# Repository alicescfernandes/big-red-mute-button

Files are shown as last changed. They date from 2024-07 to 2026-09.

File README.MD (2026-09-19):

# [WIP] 🔴 Big Red Button (BRB for short)

## A wireless bluetooth button that does anything

This is a Bluetooth-controlled device that emulates a Bluetooth mouse, allowing it to appear as a standard input device to Windows and macOS. This enables it to be paired with the OS without installing any drivers or additional software. This is the V3 version of the button, where i experimented a lot with parts and printed circuit boards!

The device uses BLE (Bluetooth Low Energy) to communicate wirelessly via Bluetooth characteristics (think of it like wireless variables) that can be changed by a device that is authenticated with the device.

## WHy & how did i build this?

What led me to redo the BRB (🔴) _again_ was the desire to make the perfect button, and that meant that v1 and v2 were not perfect. For one, the v2 project kept restarting on battery, and i just had way to many wires. The button itself was big and noisy, and used a 12V LED that i could barely see and needed a boost converter to take 5V into 12V.

For this revision, i wanted all on 5V, which meant rebuilding the button itself. Since i had a few spare keyboard Cherry MX switches and a Neoixel ring that i ended up storing away, i've settled on using those parts for this revision. For the dome part, i decided to take apart the red button of V1, and repurposed the battery of V2.

I experimented _a lot_ on this revision. Went with magnetic connectors for the bottom and top part, custom made PCBs (i designed them myself, and even milled one on a CNC device), a big (i mean _huge_) keycap for the Cherry MX with 12 powerful 5V LEDS! The "net new" parts ended up being a IP5603 module to manage the charging of the battery and a few accessory parts for the enclosure.

I ended designing 2 versions of both top and bottom PCB's, a surface mount version and a through hole version that could be milled on a CNC, I ended up designing them as a experiment and learning exercise!

### Why not TP4056?

I researched a lot about battery management IC's, and had to make a fiww design options early on, so i could find the chip that i would need. My requirements were:
- Needs a power path, meaning that it can be used while charging
- Needs to be suitable for low charging currents, or the charging current should be configurable
- Needs to be suitable for LiPo pouch cells.
- It would be nice to have I2C for battery percentage
- It would be nice to have an integrated boost converter 

After my research, ended up with a few options:  TP4056, IP5603, BQ25185, BQ25895, MCP73871 and ETA9740. They all have advantages:
- TP4046 is the simplest of them all, but doesn't transform the output of the battery to 5V, and i really need those 5V. You can definitely add a boost circuit for the output, but i didn't want to bother with that
- IP5603 does transform the power to 5V, but it only provides visual indicators for battery percentage. It's also relatively simple to build a circuit around this one. However, this chip uses a pushbutton to enable / disable the battery power and it's not suitable for LiPo pouch cells as it charges with high currents, more suitable for 18650 battery packs
- ETA9740 is very similar to IP5603, however it doesn't allow me to configure a smaller charge current than 2amps, and i need a charging rate of 300ma
- BQ25895 can provide a 5V power and battery percentage information over I2C protocol, which is awesome, but the reference circuit is a bit too scary for me to try, and it's a bit outta my league.
- BQ25185 ticks a lot of those boxes. It has a power path, i can configure to charge on low currents which makes it suitable for my LiPo cell. However, i'll have to add my own boost converter to get stable 5V and 1A out of the battery.
- MCP73871 is in some ways just a simple version of the BQ25185, with less features and a easier footprint to handle. It still needs to boost converter.

Ultimately, I decided to go with a BQ25895 +  TPS61023 combo, since i was able to find a test board that i could use on a breadboard to validate the design.

### Software used
- EasyEDA for schematic and PCB Design
- Flatcam for board milling
- Arduino IDE to code the ESP32's

#### Parts List (Bottom)
- ESP32-S3-Tiny
- BQ25185DLHR (Battery Charger)
     - configured for 300ma charge rate 
     - and 500ma input rate
     - 74438357010 Inductor (recommended by datasheet)
     - X5R Capacitors (recommended by datasheet, for cost)
- TPS61023DRLR
    - Configured for 5V, 1.1A
- L584070 (CELLEVIA) LiPo Battery
- Panel-mounted USB Port (with resistors on CC1 & CC2)

#### Parts List (Top)
- Cherry MX Red
- 12 WS2812 LEDs wired in a ring configuration 

### Detailed PCB Specs

The electronics themselves are wired on two separate PCBs: the top PCB that has the lights and buttons, and the bottom PCB handles the power and logic control. The PCB's are then connected together.

The PCB's were designed to be 2 Layers (Signal, Ground) on the bottom PCB  and 4 layers (VCC, Ground, Signal, Ground) on the Top PCB

## Inner workings

### Mouse Emulation

This device uses Bluetooth Low Energy (BLE) to emulate a mouse via the HID (Human Interface Device) profile. By creating a fake mouse, it appears to the host (Windows or macOS) as a standard mouse. And with BLE, we can create our own functionalities (custom characteristics) and attach it to the fake mouse device, and have some python code to write on those.

The fake mouse is needed for Windows and MacOS, that refuse to accept input of devices that are don't provide HID functionality, but i assure you that the mouse is controlled by the device, it just emulates the device characteristics of a mouse.

### BLE Services and Characteristics

In Bluetooth Low Energy (BLE), communication is structured around services and characteristics. A service is a collection of related functionality, like a HID service for mouse input or a battery service for reporting battery level. Each service contains one or more characteristics, which represent individual pieces of data that can be read, written, or notified.

For example, this device implements:

- A HID service, which includes characteristics to send mouse reports (movement or button presses).
- A Battery service, with a battery level characteristic which exposes the current battery level to the connected device.
- A Custom Button service, with a single characteristic which notifies the host when the physical button is pressed.

### You said it could do anything?

Yes, with the help of some python code we can make the mic mute globally, trigger a lock screen or just rick-roll somebody. The host application was built using Rumps and Python to build a menu bar GUI. I'm not sure if this is compatible with Linux and Windows but at least works on Mac (:joy:)

## Assembling one yourself

### Bill of Materials (if you wanna build it yourself)

- [Waveshare ESP32-Tiny](https://www.waveshare.com/esp32-s3-tiny.htm) or a [Seed XIAO ESP32-S3](https://www.seeedstudio.com/XIAO-ESP32S3-p-5627.html)
- [Big Dome Pushbutton](https://www.sparkfun.com/products/9181), you will need just the "dome" part
- [Adafruit BQ2185 Charger with 5V Booster](https://www.adafruit.com/product/6106) or [SeedStudio Lipo Rider Plus](https://www.seeedstudio.com/Lipo-Rider-Plus-p-4204.html), both work for Li-ion Pouch Cells, and both are USB-C
- USB power input via:
    - A USB Panel mount to 2 wires (something like this https://www.adafruit.com/product/6072, that has a red and a black wire)
    - A USB-C 5V PD decoy chip (pay attention to the 5V, it needs to be 5V)
- A Lithium Battery (mind the Amps)
- A 12 RGB LED NeoPixel (https://www.adafruit.com/product/1643)
- A Cherry MX Switch (any type)
- And a NeoKey breakout board (https://www.adafruit.com/product/4978, or you can just use a cherry mx like a simple button)

## Easy circuit to follow 

Assemble your parts like the image below

>[!IMPORTANT]
> The ground (the black wire) is a common ground. This means that all grounds need to be connected between each other

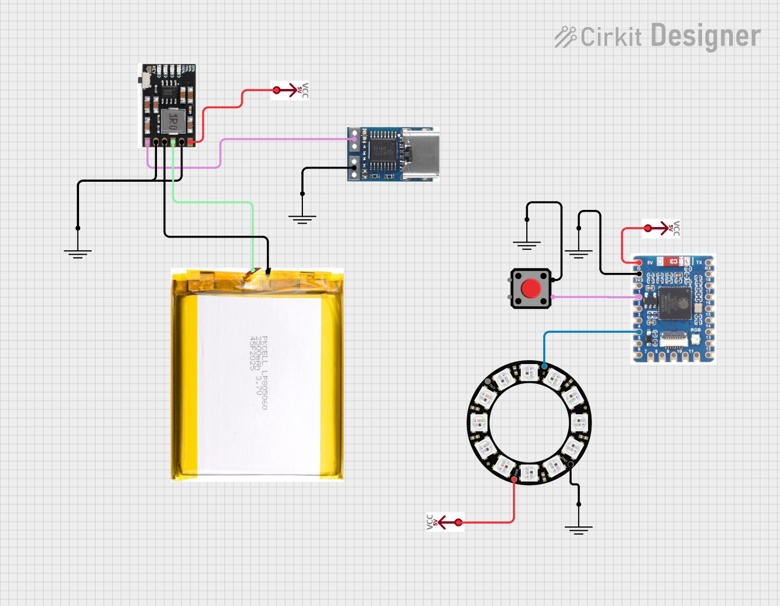
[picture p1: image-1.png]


Try to solder into a protoboard for less wires. The enclosure here won't work so you will have to adjust the enclosure to match the footprint

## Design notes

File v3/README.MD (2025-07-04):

# 🔴 Big Red ~~Mute~~ Button



## Mute that mic with Javascript or lock that computer with custom hardware!

[insert image here]

This is a Bluetooth-controlled device that emulates a mouse, allowing it to appear as a standard input device to Windows and macOS. This enables it to be paired with the OS without installing any drivers or additional software.

The device uses BLE (Bluetooth Low Energy) to communicate wirelessly and emulates a Human Interface Device (HID). This makes it possible to trigger system-level actions like muting the microphone or locking the screen by simulating mouse movement or clicks.

A large physical button sends input events wirelessly. These can be picked up by the host OS as normal mouse activity or used with automation tools to trigger specific actions.

## Mouse Emulation

This device uses Bluetooth Low Energy (BLE) to emulate a mouse via the HID (Human Interface Device) profile. By creating a fake mouse, it appears to the host (Windows or macOS) as a standard mouse. And with BLE, we can create our own functionalities (custom characteristics) and attach it to the fake mouse device, and have some python code to write on those

## BLE Services and Characteristics

In Bluetooth Low Energy (BLE), communication is structured around services and characteristics. A service is a collection of related functionality—like a HID service for mouse input or a battery service for reporting battery level. Each service contains one or more characteristics, which represent individual pieces of data that can be read, written, or notified.

For example, this device implements:

- A HID service, which includes characteristics to send mouse reports (movement or button presses).
- A Battery service, with a battery level characteristic which exposes the current battery level to the connected device.
- A Custom Button service, with a single characteristic which notifies the host when the physical button is pressed.

## Mute the mic globally (only compatible with OSX & Windows) (WIP)

With the help of some python code we can make the mic mute globally, aplication-wide. To do so, just follow the instructions below.

I'm still working on a GUI to make this a little bit easier to do, and is still a little big hardcoded

### Setup - TBD

# Parts

- Xiao ESP32C3
- [Big Dome Pushbutton](https://www.sparkfun.com/products/9181)
- Buck Converter
- Lithium Battery

# TODO:

- GUI for python

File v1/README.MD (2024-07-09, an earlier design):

# 🔴 Big Red ~~Mute~~ Button

## Mute that mic with Javascript or lock that computer with custom hardware!
[insert image here]

With the release of Chrome 80, a new web API was shipped with the browser. This API allows the browser to communicate via serial with other devices, however is behind a flag. This project makes use of that API to communicate with an Arduino Micro that opens a serial port over USB. Both are set to the 6900 baud rate, so that they can communicate with each other. 

This makes use Tampermonkey to inject a script that will allow you to connect to any device over serial, and when a connection is established, the javascript will hijack the mute button (of the DOM) and will read the status of the button, and will send a first command to the connected device. Then, with the MutationObserver API, whenever the button is clicked, it will read again the status of the button, and send over the command to the arduino. 

The arduino accepts (over serial) two string values: a '0' and a '1',when is 0 the light is turned off, and when is '1' the light is turned on. It's the browser that tells if the LED is on or off. When you press the "physical" button, the arduino will detect the press and send it over to the browser (by writing a '0' on the console), and the browser will check the current status of the mute, and toggle it.

### Setup - Tampermonkey
- Go to ``chrome://flags`` in your browser and enable the ``#enable-experimental-web-platform-features`` flag
- Restart the browser
- Install Tampermonkey extension
- Install the script of this project  (https://github.com/alicescfernandes/big-red-mute-button/raw/master/tampermonkey/mutebutton.user.js)
- Reload the browser again
- Plug in your arduino
- Upload the arduino code of this project

## Mute the mic globally (only compatible with OSX & Windows) (WIP)
With the help of some python code we can make the mic mute globally, aplication-wide. To do so, just follow the instructions below.

I'm still working on a GUI to make this a little bit easier to do, and is still a little big hardcoded
### Setup - Python (only compatible with OSX)
- `cd python/`
- `pip3 install -r requirements.txt`
- Press the button and you should be muted.

### Attention Mac Users!
If your system is High Sierra or below you may need to install the CH34X drivers on your mac. [This page](https://github.com/adrianmihalko/ch340g-ch34g-ch34x-mac-os-x-driver) explain how you can install the driver

### For M1 chips
https://arduino.stackexchange.com/a/86787

# Parts
- 2N222A Transistor 
- Xiao ESP32C3
- [Big Dome Pushbutton](https://www.sparkfun.com/products/9181)
- Buck Converter
- Lithium Battery

# TODO:
- Moving JS code into an extension
- GUI for python
# References
- [Web Serial API](https://web.dev/serial/)
- [Web Serial Codelab](https://codelabs.developers.google.com/codelabs/web-serial/#0)

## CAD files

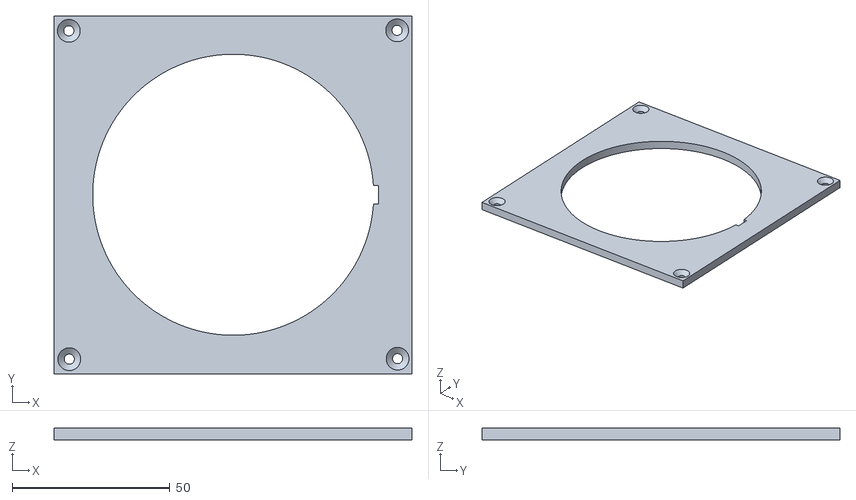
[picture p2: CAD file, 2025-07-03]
v3/cad/lid.stl
113.4 x 113.4 x 3.70

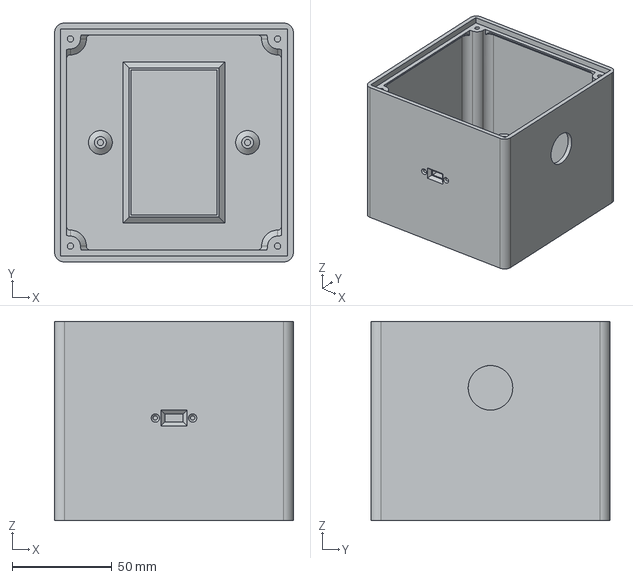
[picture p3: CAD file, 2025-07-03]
v3/cad/box.stp
120.0 x 120.0 x 100.0 mm

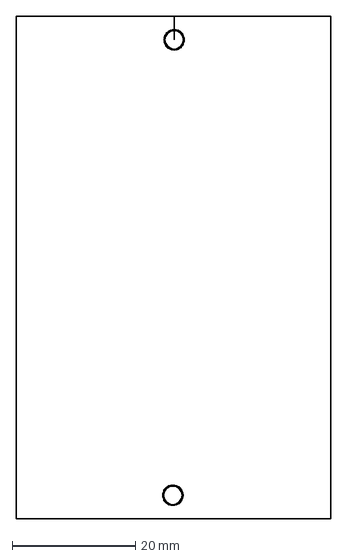
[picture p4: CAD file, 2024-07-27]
v3/cad/pcb.dxf
51.0 x 81.5 mm

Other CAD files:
v3/cad/box2.3mf
v3/cad/box.3mf
v3/cad/box.stl

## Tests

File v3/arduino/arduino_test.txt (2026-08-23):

#include <Adafruit_NeoPixel.h>

#define BUTTON D1
#define PIN_MODE INPUT_PULLUP // D1 can use the internal pull up resistor

#define NEOPIXEL_PIN D9
#define NUMPIXELS 12

Adafruit_NeoPixel pixels(NUMPIXELS, NEOPIXEL_PIN, NEO_GRB + NEO_KHZ800);
#define DELAYVAL 175

// Sketch to setup the individual components before bringing in the bluetooth code
// it's also a good small scale test for the button and light components

void setup() {
  // Setup the pushbutton as an input and enable internal pullup
  pinMode(BUTTON, PIN_MODE);

  // Setup Serial Port
  Serial.begin(9600);

  pixels.begin();

}

void loop() {
  // Print pushbutton state to serial monitor
  int buttonRead = 1 - digitalRead(BUTTON); 
  Serial.println(buttonRead);
  
  // Neopixel code
  pixels.clear();

  for(int i=0; i<NUMPIXELS; i++) {
    pixels.setPixelColor(i, pixels.Color(255, 255, 255)); // RGB
  }
  
  pixels.show();
  // #endregion

}

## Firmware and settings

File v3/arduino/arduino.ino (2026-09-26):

#include <NimBLEDevice.h>
#include <Adafruit_NeoPixel.h>
#include <Preferences.h>
#include "secrets.h"
#include "constants.h"

volatile unsigned long last_debounce = 0;
static unsigned long debounce_delay = 260;  // the debounce time; increase if the output flickers


bool animate_button_state = false;
bool device_connected_state = false;
// https://forum.arduino.cc/t/explanation-of-volatile/402932
volatile bool button_state = false;                   // state triggered phisically via button. written inside a interrupt
volatile bool standby_state = false;                  // sleep state only activated via software. written inside a interrupt
volatile bool write_to_characteristic_state = false;  // written inside a interrupt
volatile int brightness_state;                 // sleep state only activated via software. written inside a interrupt


int blink_cycles_done = 0;     // number of completed on-off blinks
bool blink_led_state = false;  // current state within a cycle
unsigned long blink_last_changed = 0;


int getUserBrightness() {
  if(brightness_state){
    return brightness_state;
  }
  
  int value = preferences.getInt(
    PREFERENCE_KEY,
    PREFERENCE_DEFAULT_VALUE
  );

  brightness_state = constrain(value, 0, 255);
  return brightness_state;
}

void setUserBrightness(int value) {
  int safe_value = constrain(value, 0, 255);
  preferences.putInt(PREFERENCE_KEY, safe_value);
  brightness_state = value;
}

int read_value(NimBLECharacteristic *c) {
  time_t timestamp;
  NimBLEAttValue stuff = btn_characteristic->getValue();  // timestamp optional
  const uint8_t *value = stuff.getValue(&timestamp);
  return (int)value[0];
}

void write_value(NimBLECharacteristic *c, int value) {
  c->setValue(byte(value));
  c->notify();
}

// Call every on loop with 1 of the 3 animations.
// Returns true while still animating, false once finished
// IN_OUT never finishes on its own
bool breatheStep(BreatheMode mode, unsigned long interval = 5) {
  static unsigned long lastUpdate = 0;
  static BreatheMode lastMode = BREATHE_IN;
  int maxBrightness = getUserBrightness();

  // Reset state whenever the mode changes (fresh start each time it's selected)
  if (mode != lastMode) {
    lastMode = mode;
    switch (mode) {
      case BREATHE_IN:
        brightness = 0;
        step = 1;
        break;
      case BREATHE_OUT:
        brightness = maxBrightness;
        step = -1;
        break;
      case BREATHE_IN_OUT:
        brightness = 0;
        step = 1;
        break;
    }
  }

  unsigned long now = millis();
  if (now - lastUpdate >= interval) {
    lastUpdate = now;

    brightness += step;

    // Reverse direction only in IN_OUT mode
    if (mode == BREATHE_IN_OUT) {
      if (brightness >= maxBrightness) {
        brightness = maxBrightness;
        step = -1;
      } else if (brightness <= 0) {
        brightness = 0;
        step = 1;
      }
    } else {
      brightness = constrain(brightness, 0, maxBrightness);
    }

    pixels.setBrightness(brightness);
    for (int i = 0; i < NUMPIXELS; i++) {
      pixels.setPixelColor(i, pixels.Color(255, 255, 255));
    }
    pixels.show();
  }

  if (mode == BREATHE_IN) return brightness != maxBrightness;
  if (mode == BREATHE_OUT) return brightness != 0;

  return true;
}

void resetState() {
  animate_button_state = false;
  blink_cycles_done = 0;
  blink_led_state = false;
  button_state = false;
  write_to_characteristic_state = false;
  standby_state = false;

  // Reset pixel colors
  updateNeoPixelBrightness();

  // resets the bluetooth state
  write_value(btn_characteristic, 0);
  write_value(standby_characteristic, 0);
}

class ServerCallbacks : public NimBLEServerCallbacks {
public:
  void onConnect(NimBLEServer *pServer, NimBLEConnInfo &connInfo) {
    device_connected_state = true;

    Serial.println("connected");
    Serial.print("Client address: ");
    Serial.println(connInfo.getAddress().toString().c_str());
  }

  void onDisconnect(NimBLEServer *pServer, NimBLEConnInfo &connInfo, int reason) {
    device_connected_state = false;

    Serial.println("disconnected");
    resetState();

    // Restart advertising so the device can connect again
    NimBLEDevice::startAdvertising();
  }
};


class RedButtonCallbacks : public NimBLECharacteristicCallbacks {
public:
  void onWrite(
    NimBLECharacteristic *pCharacteristic,
    NimBLEConnInfo &connInfo) {
    NimBLEAttValue value = pCharacteristic->getValue();
    Serial.print("Written to:");
    Serial.println(pCharacteristic->getUUID().toString().c_str());

    if (pCharacteristic->getUUID().equals(NimBLEUUID(BTN_CHARACTERISTIC)) && standby_state == false) {
      // handle button write
      if (value.size() > 0) {
        button_state = value[0] != 0;
        animate_button_state = true;
      }
    }

    if (pCharacteristic->getUUID().equals(NimBLEUUID(STANDBY_CHARACTERISTIC))) {
      // handle standby write
      if (value.size() > 0) {
        standby_state = value[0] != 0;      }
        if(standby_state){
          // update the neo pixel brigthess outside of the loop
          updateNeoPixelBrightness();
        }
    }

    if (pCharacteristic->getUUID().equals(NimBLEUUID(BRIGHTNESS_CHARACTERISTIC))) {
      // handle standby write
      int currentValue = getUserBrightness(); 
      if (value.size() > 0 && currentValue != value[0]) {
        setUserBrightness(value[0]);
        Serial.print("Attepmted to write new brightness:");
        Serial.print(value[0]);
      }
    }
  }
};



void create_hid_service() {
  NimBLEService *hidService = ble_server->createService("1812");  // HID service

  // HID Info
  const uint8_t hidInfo[] = { 0x01, 0x01, 0x00, 0x02 };
  hidService->createCharacteristic("2A4A", NIMBLE_PROPERTY::READ_ENC | NIMBLE_PROPERTY::READ_AUTHEN)->setValue(hidInfo, sizeof(hidInfo));

  // HID Report Map
  hidService->createCharacteristic("2A4B", NIMBLE_PROPERTY::READ_ENC | NIMBLE_PROPERTY::READ_AUTHEN)->setValue(hidReportDescriptor, sizeof(hidReportDescriptor));

  // HID Control Point
  const uint8_t ctrl[] = { 0x00 };
  hidService->createCharacteristic("2A4C", NIMBLE_PROPERTY::WRITE_NR)->setValue(ctrl, sizeof(ctrl));

  // Protocol Mode
  const uint8_t proto[] = { 0x01 };
  hidService->createCharacteristic("2A4E", NIMBLE_PROPERTY::READ | NIMBLE_PROPERTY::WRITE_NR)->setValue(proto, sizeof(proto));

  // Input Report characteristic (required by macOS)
  NimBLECharacteristic *inputReport = hidService->createCharacteristic("2A4D", NIMBLE_PROPERTY::READ_ENC | NIMBLE_PROPERTY::NOTIFY | NIMBLE_PROPERTY::READ_AUTHEN);
  const uint8_t dummyInput[] = { 0x00, 0x00, 0x00 };  // dummy mouse report
  inputReport->setValue(dummyInput, sizeof(dummyInput));
  inputReport->createDescriptor("2908", NIMBLE_PROPERTY::READ)->setValue(std::vector<uint8_t>{ 0x01, 0x01 });  // Report ID 1, input

  hidService->start();
}

// https://www.bluetooth.com/specifications/dis-1-2/
void create_dis_service() {
  // Create device info service (DIS)
  NimBLEService *service = ble_server->createService("180A");

  // Create Manufacturer Name String characteristic, read only
  NimBLECharacteristic *characteristic = service->createCharacteristic("2A29", NIMBLE_PROPERTY::READ);
  characteristic->setValue("Alice Fernandes");

  service->start();
}

void create_box_service() {
  NimBLEService *service = ble_server->createService(BUTTON_SERVICE_UUID);
  NimBLECharacteristicCallbacks* redButtonCallbacks = new RedButtonCallbacks();

  // Button status
  btn_characteristic = service->createCharacteristic(BTN_CHARACTERISTIC, NIMBLE_PROPERTY::READ | NIMBLE_PROPERTY::WRITE | NIMBLE_PROPERTY::READ_ENC | NIMBLE_PROPERTY::WRITE_ENC | NIMBLE_PROPERTY::READ_AUTHEN | NIMBLE_PROPERTY::WRITE_AUTHEN | NIMBLE_PROPERTY::NOTIFY);
  btn_characteristic->setValue(byte(0));  // Clients can subscribe to this, and update as they wish
  btn_characteristic->setCallbacks(redButtonCallbacks);

  // Add the 0x2901 User Description descriptor
  NimBLEDescriptor *btn_description = btn_characteristic->createDescriptor("2901", NIMBLE_PROPERTY::READ | NIMBLE_PROPERTY::READ_ENC, 100);
  btn_description->setValue("Button  status (pressed / not pressed)");


  //  Control Standby animation
  standby_characteristic = service->createCharacteristic(STANDBY_CHARACTERISTIC, NIMBLE_PROPERTY::READ | NIMBLE_PROPERTY::WRITE | NIMBLE_PROPERTY::READ_ENC | NIMBLE_PROPERTY::WRITE_ENC | NIMBLE_PROPERTY::READ_AUTHEN | NIMBLE_PROPERTY::WRITE_AUTHEN | NIMBLE_PROPERTY::NOTIFY);
  standby_characteristic->setValue(byte(0));  // Clients can subscribe to this, and update as they wish
  standby_characteristic->setCallbacks(redButtonCallbacks);

  // Add the 0x2901 User Description descriptor
  NimBLEDescriptor *standby_description = standby_characteristic->createDescriptor("2901", NIMBLE_PROPERTY::READ | NIMBLE_PROPERTY::READ_ENC, 100);
  standby_description->setValue("Standby Mode (0 or 1)");

  // Control LED brightness
  brightness_characterstic = service->createCharacteristic(BRIGHTNESS_CHARACTERISTIC, NIMBLE_PROPERTY::READ | NIMBLE_PROPERTY::WRITE | NIMBLE_PROPERTY::READ_ENC | NIMBLE_PROPERTY::WRITE_ENC | NIMBLE_PROPERTY::READ_AUTHEN | NIMBLE_PROPERTY::WRITE_AUTHEN | NIMBLE_PROPERTY::NOTIFY);
  brightness_characterstic->setValue(getUserBrightness());  // Clients can subscribe to this, brightness_characterstic update as they wish
  brightness_characterstic->setCallbacks(redButtonCallbacks);

  // Add the 0x2901 User Description descriptor
  NimBLEDescriptor *brightness_description = brightness_characterstic->createDescriptor("2901", NIMBLE_PROPERTY::READ | NIMBLE_PROPERTY::READ_ENC, 100);
  brightness_description->setValue("Light Brightness (0-255)");

  service->start();
}


void on_button_click() {
  unsigned long current_time = millis();
  if (current_time - last_debounce > debounce_delay && standby_state == false) {
    button_state = !button_state;
    write_to_characteristic_state = true;  // writing a characterstic inside of interrupt breaks XIAO
    last_debounce = current_time;
  }
}

void updateNeoPixelBrightness() {
  pixels.setBrightness(getUserBrightness());
}

void setupNeoPixel() {
  pixels.begin();
  updateNeoPixelBrightness();
  pixels.show();
}


// Call this every loop() until it returns false (animation done)
// Call every loop().
// To start: blink_cycles_done = 0; blink_led_state = false;
// Returns true while blinking, false when idle/done.
void showAll() {
  updateNeoPixelBrightness();
  for (int i = 0; i < NUMPIXELS; i++) {
    pixels.setPixelColor(i, pixels.Color(255, 255, 255));
  }
  pixels.show();
}

void hideAll() {
  pixels.setBrightness(0);
  pixels.clear();
  pixels.show();
}

bool blinkTwice() {
  if (blink_cycles_done >= 2) {
    return false;  // done
  }

  unsigned long now = millis();
  if (now - blink_last_changed >= blinkInterval) {
    blink_last_changed = now;
    blink_led_state = !blink_led_state;

    if (blink_led_state) {
      showAll();
    } else {
      hideAll();
      blink_cycles_done++;
    }
  }

  return true;  // still blinking
}

void setup() {
  Serial.begin(115200);

  // Setup the preferences
  preferences.begin("red-button", false);
  getUserBrightness(); // initialize the variable

  NimBLEDevice::init(NAME);

  pinMode(RED_BTN, INPUT_PULLUP);
  // NimBLEDevice::deleteAllBonds();  // Dev Only

  NimBLEDevice::setSecurityAuth(true, true, true);
  NimBLEDevice::setSecurityPasskey(PASSKEY);
  NimBLEDevice::setSecurityIOCap(BLE_HS_IO_DISPLAY_ONLY);

  ble_server = NimBLEDevice::createServer();
  ble_server->setCallbacks(new ServerCallbacks());

  create_hid_service();
  create_dis_service();
  create_box_service();

  NimBLEAdvertising *advertising = NimBLEDevice::getAdvertising();
  advertising->addServiceUUID("1812");               // HID Service
  advertising->addServiceUUID(BUTTON_SERVICE_UUID);  // your custom service
  advertising->setName(NAME);                        // device name

  // Optional: set scan response data instead of setScanResponse(true)
  NimBLEAdvertisementData scanData;
  scanData.setName(NAME);
  advertising->setScanResponseData(scanData);

  // Optional: set preferred connection intervals (if your core supports it)
  // advertising->setMinInterval(0x06);  // 7.5 ms
  // advertising->setMaxInterval(0x12);  // 22.5 ms

  advertising->start();

  attachInterrupt(digitalPinToInterrupt(RED_BTN), on_button_click, RISING);

  setupNeoPixel();

  // Setup the MCU pixel
  mcuPixel.begin();
  mcuPixel.setBrightness(64);  // Approximately 25%

}



void loop() {
  blinkMcuPixel(device_connected_state);
  /* #region Bluetooth Button */
  if (device_connected_state) {

    if (blink_cycles_done < 2) {
      blinkTwice();
    }

    if (write_to_characteristic_state) {
      write_to_characteristic_state = false;
      animate_button_state = true;
      Serial.println("wrote to char");
      Serial.println(button_state ? HIGH : LOW);
      int characteristic_value = button_state ? 1 : 0;
      write_value(btn_characteristic, characteristic_value);
    }

    if (animate_button_state) {
      animate_button_state = breatheStep(button_state ? BREATHE_IN : BREATHE_OUT, 1);
    }

    if (standby_state) {
      updateStandbyAnimation();
    }
  }
  /* #endregion */

  // use the standby animations as the "holding pattern" while we wait for connection
  // the mcu's led will be the status LED instead
  if (!device_connected_state) {
      updateStandbyAnimation();
  }
}

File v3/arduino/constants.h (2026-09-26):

#define RED_BTN 1

#define NEOPIXEL_PIN 4
#define NUMPIXELS 12
#define MCU_PIN 38
#define PREFERENCE_KEY "brightness"
#define PREFERENCE_DEFAULT_VALUE 255


const uint8_t hidReportDescriptor[] = {
  0x05, 0x01,  // Usage Page (Generic Desktop)
  0x09, 0x02,  // Usage (Mouse)
  0xA1, 0x01,  // Collection (Application)
  0x09, 0x01,  //   Usage (Pointer)
  0xA1, 0x00,  //   Collection (Physical)
  0x05, 0x09,  //     Usage Page (Buttons)
  0x19, 0x01,  //     Usage Minimum (1)
  0x29, 0x03,  //     Usage Maximum (3)
  0x15, 0x00,  //     Logical Minimum (0)
  0x25, 0x01,  //     Logical Maximum (1)
  0x95, 0x03,  //     Report Count (3)
  0x75, 0x01,  //     Report Size (1)
  0x81, 0x02,  //     Input (Data, Variable, Absolute)
  0x95, 0x01,  //     Report Count (1)
  0x75, 0x05,  //     Report Size (5)
  0x81, 0x01,  //     Input (Constant)
  0x05, 0x01,  //     Usage Page (Generic Desktop)
  0x09, 0x30,  //     Usage (X)
  0x09, 0x31,  //     Usage (Y)
  0x15, 0x81,  //     Logical Minimum (-127)
  0x25, 0x7F,  //     Logical Maximum (127)
  0x75, 0x08,  //     Report Size (8)
  0x95, 0x02,  //     Report Count (2)
  0x81, 0x06,  //     Input (Data, Variable, Relative)
  0xC0,        //   End Collection
  0xC0         // End Collection
};

Adafruit_NeoPixel pixels(NUMPIXELS, NEOPIXEL_PIN, NEO_GRB + NEO_KHZ800);

Adafruit_NeoPixel mcuPixel(1, MCU_PIN, NEO_GRB + NEO_KHZ800);

NimBLEServer *ble_server;
NimBLECharacteristic *btn_characteristic;
NimBLECharacteristic *standby_characteristic;
NimBLECharacteristic *brightness_characterstic;



enum BreatheMode { BREATHE_IN,
                   BREATHE_OUT,
                   BREATHE_IN_OUT };

int brightness = 0;
int step = 1;

const unsigned long blinkInterval = 150;  // ms per half-cycle (on or off)

Preferences preferences;

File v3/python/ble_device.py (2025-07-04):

from bleak import BleakClient, BleakScanner
from dotenv import load_dotenv
from controls.lock_control import LockControl

import asyncio
import logging
import sys
import os

load_dotenv()  # This line brings all environment variables from .env into os.environ

BATTERY_CHARACTERISTIC = os.environ['BATTERY_CHARACTERISTIC']
BUTTON_CHARACTERISTIC = os.environ['BUTTON_CHARACTERISTIC']
PASS_CODE = os.environ['PASS_CODE']
DEVICE_NAME = os.environ['DEVICE_NAME']

# Set up logging
logging.basicConfig(level=logging.INFO)
logger = logging.getLogger(__name__)

class BleDevice():
    def __init__(self, loop=None):
        self.client = None
        self.loop = loop
    def turn_on(self):
        """
        Called as a sync callback, but dispatches an async task.
        """
        logger.info("Turning on the device...")

        async def main():
            try:
                logger.error("write to GATT characteristic")
                await self.client.write_gatt_char(BUTTON_CHARACTERISTIC, b'\x01')
            except Exception as e:
                logger.error(f"Failed to write to GATT characteristic: {e}")

        # asyncio.run_coroutine_threadsafe(main(), self.loop)
        

    def turn_off(self):
        """
        Called as a sync callback, but dispatches an async task.
        """
        logger.info("Turning off the device...")

        async def main():
            try:
                logger.error("write to GATT characteristic")
                await self.client.write_gatt_char(BUTTON_CHARACTERISTIC, b'\x00')
            except Exception as e:
                logger.error(f"Failed to write to GATT characteristic: {e}")

        # asyncio.run_coroutine_threadsafe(main(), self.loop)

    async def close(self):
        """
        Close the connection to the device
        """
        if self.client and self.client.is_connected:
            await self.client.disconnect()
            logger.info("Disconnected from the device")
        else:
            logger.info("No active connection to close")

    def isOpen(self):
        """
        Check if the connection to the device is open
        """
        if self.client:
            return self.client.is_connected
        return False

    async def connect_with_context(self,address, onRead):
        """
        Connect to the device and set up notifications with a callback
        """
        self.client = BleakClient(address)
        try:
            await self.client.connect()
            logger.info("Connected to the device")
            await self.client.start_notify(BUTTON_CHARACTERISTIC, onRead)
            logger.info(f"Started notifications on {BUTTON_CHARACTERISTIC}")
        except Exception as e:
            logger.error(f"Failed to connect: {e}")
            await self.close()

        while self.client.is_connected:
            await asyncio.sleep(1)
        

    async def connect(self,address):
        """
        Connect to the device
        """
        self.client = BleakClient(address)
        try:
            await self.client.connect()
            logger.info("Connected to the device")

            # Keep the script running to receive notifications
                
        except Exception as e:
            logger.error(f"Failed to connect: {e}")
            await self.close()
        

    async def subscribe(self, address, onRead):
        await self.client.start_notify(address, onRead)

    async def get_address_for_name(self, name):
        devices = await self.list_devices()
        for d in devices:
            if(d.name == name):
                return d.address

    async def list_devices(self):
        """
        List all BLE devices
        """
        devices = await BleakScanner.discover(timeout=5)
        # for d in devices:
        #    print(f"{d.name} ({d.address})")

        return devices

if __name__ == "__main__":
    device_control = LockControl()
    
    def battery_callback_fn(char, byte_array):
        logger.debug(f"Notification from {char}: {byte_array}")
        status = int.from_bytes(byte_array)
        print("Battery", status)
            
    def button_callback_fn(char, byte_array):
        logger.debug(f"Notification from {char}: {byte_array}")
        status = int.from_bytes(byte_array)
        print("Button", status)
        if(status == 1):
            device_control.lock()
            
    args = sys.argv[1:]

    async def main(args):
        loop = asyncio.get_running_loop()  # <- pega o loop atual
        device = BleDevice(loop)
        address = await device.get_address_for_name("BigRedButton")
        await device.list_devices()
        # await device.connect(address)
        # await device.subscribe(BUTTON_CHARACTERISTIC, button_callback_fn)
        
        device_control.check_status(device.turn_on, device.turn_off, interval_ms=250)
        
        while device.isOpen():
            await asyncio.sleep(1)

    asyncio.run(main(args))

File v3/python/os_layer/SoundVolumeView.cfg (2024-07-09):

[General]
MarkOddEvenRows=0
ShowGridLines=0
SaveFilterIndex=0
ShowInfoTip=1
AutoRefresh=1
TrayIcon=0
StartAsHidden=0
SortOnEveryUpdate=0
MainFont=00 00 00 00 00 00 00 00 00 00 00 00 00 00 00 00 00 00 00 00 00 00 00 00 00 00 00 00 00 00 00 00 00 00 00 00 00 00 00 00 00 00 00 00 00 00 00 00 00 00 00 00 00 00 00 00 00 00 00 00 00 00 00 00 00 00 00 00 00 00 00 00 00 00 00 00 00 00 00 00 00 00 00 00 00 00 00 00 00 00 00 00
AlwaysOnTop=0
AutoSizeColumnsOnUpdate=0
SaveFileEncoding=0
MouseWheelMode=2
MouseWheelPercentChange=5
ShowDisabledDevices=0
ShowUnpluggedDevices=0
AlignNumbersToRight=0
SelectedChannel=0
WinPos=2C 00 00 00 00 00 00 00 01 00 00 00 00 83 FF FF 00 83 FF FF FF FF FF FF FF FF FF FF EA 00 00 00 EA 00 00 00 6A 03 00 00 CA 02 00 00
Columns=96 00 00 00 78 00 01 00 5A 00 02 00 96 00 03 00 64 00 04 00 64 00 05 00 64 00 06 00 64 00 07 00 64 00 08 00 78 00 09 00 78 00 0A 00 78 00 0B 00 78 00 0C 00 78 00 0D 00 5E 01 0E 00 5E 01 0F 00 5E 01 10 00 96 00 11 00 96 00 12 00 2C 01 13 00 64 00 14 00 96 00 15 00 FA 00 16 00
Sort=4100
[RecentFiles]
0=
1=
2=
3=
4=
5=
6=
7=
8=
9=

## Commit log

2021-12-21 arduino sketch
2021-12-21 wiring; more code
    [wiring.fzz]
2021-12-21 add windows compat
    [SoundVolumeView.cfg]
2021-12-25 more mac code
    [SoundVolumeView.cfg]
2023-03-04 adds lock controls to the big red mute; adds a simple taskbar app to control this
    [SoundVolumeView.cfg]
2023-03-04 adds m1 chip driver
2024-07-09 move to folder
    [SoundVolumeView.cfg, wiring.fzz]
2024-07-09 adds python code
    [SoundVolumeView.cfg]
2024-07-15 more stuff 2
    [fritzing.fzz]
2024-07-15 adds battery round to 5
2024-07-19 adds cad designs
2024-07-20 adds status led; more cad design
    [permaproto.fzz]
2024-07-21 adds more cad
2024-07-27 adds more cad & changes pin to D9
    [pcb.dxf]
2025-07-03 more cad
    [box.3mf, box.stl, box.stp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]
2025-07-03 adds fake mouse so it presents as a HID device
2025-07-04 adds more code - reverts some of him
    [ble_device.py]
2026-08-23 duplicate v2 folder into v3
    [SoundVolumeView.cfg, box.3mf, box.stl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]
2026-08-23 remove the battery service
2026-08-23 add the neopixel interaction & button into the ble code
2026-08-23 fix the notify that was always triggering with 0x01
    [arduino.ino]
2026-08-30 refactoring arduino (i'll need those 5v); circuit iterations
    [fritzing.fzz]
2026-08-30 animate button on ble write
2026-08-31 add a standby state that ignores all of the button clicks
    [fritzing.fzz]
2026-08-31 fix the values written inside interrupts; clean up dead code
    [arduino.ino]
2026-09-01 test the code on the new board; update pins; update animation speeds
2026-09-12 added last version of schematics
2026-09-12 adds more schematics; and datasheets for future reference
2026-09-12 more schematic
2026-09-15 more schematics & datasheets
2026-09-15 adds better clearance for pcb milling
2026-09-15 larger traces for pcb milling
2026-09-15 adds cnc milling tip
2026-09-15 adds no connects on pth version, and adjusts clearance for ground & traces for pcb milling
2026-09-19 more schematics
2026-09-19 i don't know which board to pick :(
2026-09-26 adds user brightness; uses mcu's status led
